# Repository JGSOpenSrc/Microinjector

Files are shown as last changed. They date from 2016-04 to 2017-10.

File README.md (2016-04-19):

# Microinjector
This repository contains the design files for a 3-D printable open hardware automated syringe pump, along with software to control the syringe pump over a serial port connection or via TTL logic. The original designs were published in a paper on the online journal PLOS ONE, and there are submodules of the relelvant repositories here.
# About
The design presented here is intended to allow for precise injection of liquid volumes from a high quality syringe with microliter precision (hence the name, microinjector). However the mechanical designs are easily adapted to syringes of other sizes (see the linear_actuator scripts or check out the submodules for more info).

The software in control runs on an Arduino in tandem with an Adafruit Motorshield (V2), using the motor shield library. Currently, calibration is performed by performing manual trials and tuning static constants in the arduino sketch to achieve desired levels of accuracy.

# Dependencies
- OpenSCAD is required to generate the models from the .scad files. You can download it from www.openscad.org.

- The Arduino IDE is required to compile and download the control script to the hardware (unless that is you have your own toolchain). Download it from www.arduino.c.

- The Adafruit Motor Shield e(VERSION 2!!) is needed to control the stepper motor used in the actuator. The best way to get it is grab it from github, to get it go to your arduino libraries folder and execute the command:

git clone https://github.com/adafruit/Adafruit_Motor_Shield_V2_Library Adafruit_Motorshield

# User's Guide #
The injector is controlled using the two limit switches, and either an open-drain (TTL) connection or a serial port connection (such as USB). The front limit switch is used to "prime" the injector, bringing it out of the reset state, and the rear limit switch is used to reset the position of the injector. The TTL pin and serial port are used to issue injection commands to the injector.

## Key Terms ##
- Zero-stroke: a configuration where the carriage is pressed up against the rear limit switch, at the motor end of the injector.
- Mid-stroke: a configuration where the carriage is in between the rear and front limit switch.
- Full-stroke: a configuration where the carriage is pressed up against the front limit switch, at the syringe end of the injector.
- Halt: a state where the injector is not primed and will ignore any injection commands. The halt state occurrs following reset, or once the injector reaches the zero-stroke or mid-stroke position
- Wait: a state where the injector is primed and will accept an injection command. The wait state occurrs when the front limit switch is pressed while in the halt state. Note, the injector must be in either the mid-stroke or zero-stroke position.

## Priming the Injector ##
After powering on, or following the assertion of reset, the injector will enter the halt state and will ignore any incoming injection request. To prime the injector, press the front limit switch once; this will put the injector in the wait state.

## Injecting via Serial Command ##
The serial port is configured run at 115200 baud, with 8 data bits, 1 stop bit, and null parity. To request an injection, send the string "inject" (without quotations) followed by a newline character.

## TTL Injection Trigger ##
The TTL pin interface is a two wire connection (signal and ground). An injection request is interpreted as a high-to-low transition on digital pin 5. The pin has an internal pull-up resistor and is 5V or 3V3 tolerant.

## Calibrating the IR Sensor ##
The injector uses an infrared emitter-detector pair to control the injection volume. Following an injection request, the motor will step forward until liquid is detected. While in the wait state, if the liquid remains for a certain amount of time then the injector will withdraw the liquid. This delay is set by a constant in the control.ino sketch.

The sensor consists of a photo-diode emitter and a photo-transistor detector. The detector is wired as an open-collector output; hence, when there is high IR absorption between the pair, the output of the sensor is a higher voltage, while when there is low absorption, the output of the sensor is a lower voltage.

For the sensor to work properly, two constants need to be calibrated in the control.ino sketch. 
- `const int high_to_low = ; // a low threshold, used to detect the presence of liquid`
- `const int low_to_high = ; // a high threshold, used to detect the absence of liqui`

Following reset, the injector will compute an average of ten IR readings, and determine the initial state of the liquid. If the average value is between the two thresholds, then the injector will not run (since it cannot determine the initial state). The average reading and the inferred initial state is printed to the serial port on every startup, and this output can be used to calibrate or troubleshoot the IR sensor.

## Wiring Configuration ##
For the injector to operate properly, there are three components that need to be connected to the arduino: the stepper motor, the limit switches, and the infrared liquid sensor.

### Motor Connection ###
The stepper motor uses a four wire bi-polar connection to the motor shield.

Motor Wire | Arduino Terminal
-----------|-----------------
Green      | M1
Black      | GND
Blue       | GND
Red        | M2

### Limit Switches ###
The limit switches connect to the motor shield by a split-end ribbon cable. The wires of the ribbon are numbered sequentially starting with the red wire being 1.

Ribbon Wire | Arduino pin
------------|------------
1           | GND
2           | Digital pin 10
3           | Digital pin 9

### IR Sensor ###
The infrared sensor is a 3 wire interface, consisting of 5V, GND, and an analog input.

Connector Position | Wire Color | Arduino Pin
-------------------|------------|------------
1                  | Black      | GND
2                  | White      | 5V
3                  | Grey       | Analog pin 0

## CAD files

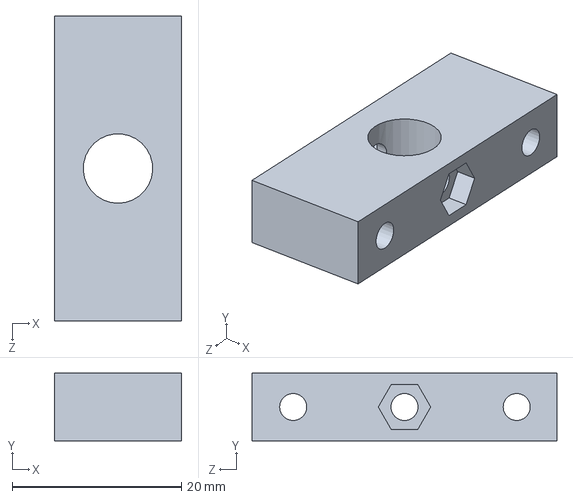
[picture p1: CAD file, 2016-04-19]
solidworks/limit_switch_block.SLDPRT
15.0 x 8.00 x 36.0 mm

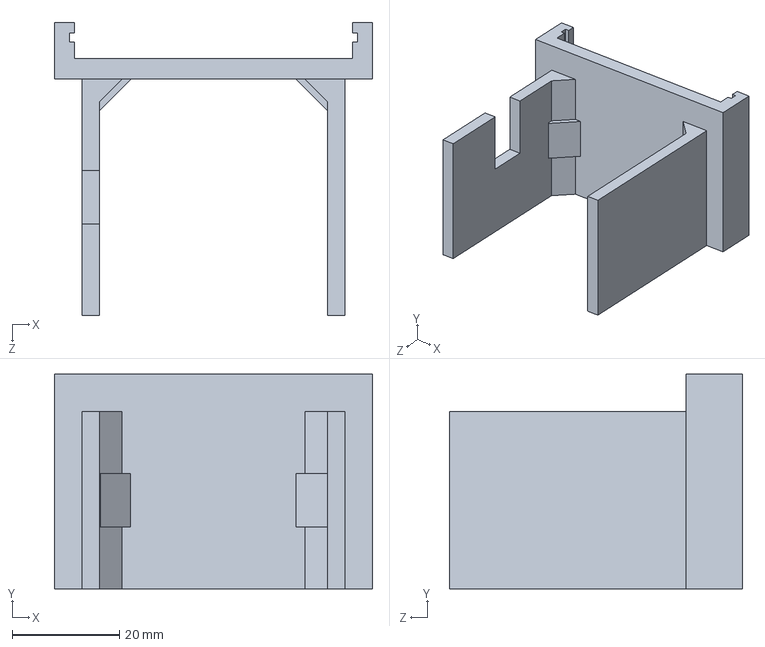
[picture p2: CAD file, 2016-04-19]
solidworks/arduino_mount.SLDPRT
59.2 x 40.0 x 54.5 mm

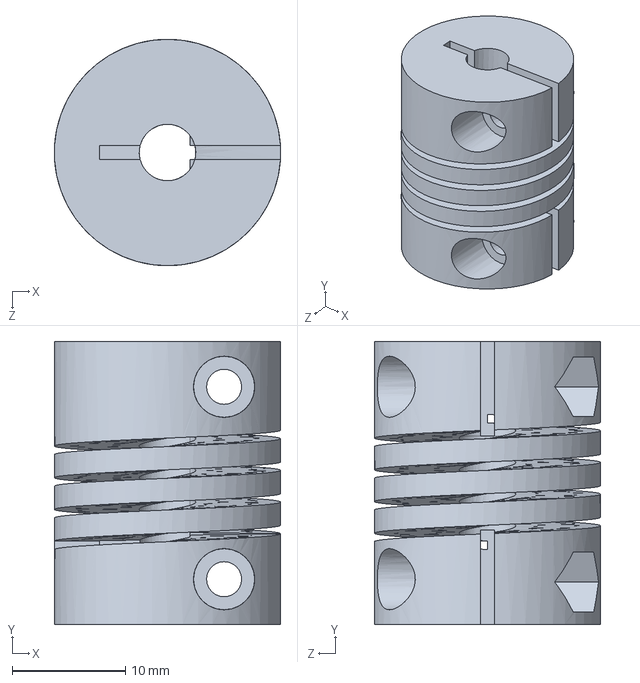
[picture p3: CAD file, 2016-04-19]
solidworks/shaft_coupler.SLDPRT
20.0 x 25.0 x 20.0 mm

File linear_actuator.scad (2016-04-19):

// Copyright 2013 Michigan Technological University
// Author: Jerry Anzalone
// This design was developed as part of a project with
// the Michigan Tech Open Sustainability Technology Research Group
// http://www.appropedia.org/Category:MOST
// It is released under CC-BY-SA
// includes may be found at http://github.com/mtu-most/most-scad-libraries

include<most-scad-libraries/fasteners.scad>
include<most-scad-libraries/steppers.scad>
include<most-scad-libraries/bearings.scad>

$fn = 96;

render_part(5);

module render_part(part_to_render) {
	if (part_to_render == 1) end_motor();

	if (part_to_render == 2) end_idler();

	if (part_to_render == 3) carriage();

	if (part_to_render == 4) carriage_syringe_pump();

	if (part_to_render == 5) clamp_syringe_pump();

	if (part_to_render == 6) {
		for (i = [-1, 1])
			translate([i * (d_guide_rod + 2.5), 0, 0])
				syringe_hook();
	}

	if (part_to_render == 7) {syringe_plunger_retainer();}

	if (part_to_render == 8) syringe_bungie();
}

// [x, y, z] = [l, w, t]

/*

No moving motor!
Simple loading
Simple cleaning
Protect motor
Secure plunger

*/

d_nozzle = 0.75;

motor = NEMA17;
cc_guides = 65;

d_lead_screw = d_M5_screw;
d_lead_nut = d_M5_nut;
h_lead_nut = h_M5_nut;
od_antibacklash_spring = 7;
l_antibacklash_spring = 9;

offset_guides = 3.5; // offset from centerline of motor shaft towards top (+y)
d_guide_rod = 8.2; // 8mm guide rods
guide_bearing = bearing_lm8uu;
pad_guide_bearing_radius = 3;

pad_guide_ends = 3; // backing material behind ends of guide rods
pad_guide_radius = 3; // material surrouding guide rods and bearings
t_motor_mount = 12;
w_ends = motor[0];
l_ends = cc_guides + d_guide_rod + 2 * pad_guide_radius;
xy_aspect = l_ends / w_ends; // needed to scale rounded box
t_motor_end = 25;
idler = bearing_625;
t_idler_end = 20;

t_carriage = guide_bearing[2] + 6;
t_syringe_clamp = 5;


d_clamp_screw = d_M3_screw;
d_clamp_screw_cap = d_M3_cap;
d_clamp_screw_nut = d_M3_nut;

// following for attachments


// syringe pump:
d_plunger = 9.5; // diameter of the plunger end
d_syringe = 8.2; // diameter of the syringe body - sets size of syringe holder
t_hook = 3; // thickness of the hook for securing syringe to actuator
t_syringe_flange = 2.85; // thickness of the rim around the diameter of the syringe near the punlger
standoff = 0.8 * t_syringe_flange;
d_plunger_max = 16; // this sets the spacing for screws on the plunger retainer and carriage
d_plunger_retainer = d_plunger_max + 12;


module end_motor() {
	difference() {
		union() {
			rod_clamps(t_motor_end, pad_guide_ends);

			// motor plate
			difference () {
				translate([0, 0, (t_motor_mount - t_motor_end) / 2])
					cube([l_ends - (l_ends - cc_guides) - 1, w_ends, t_motor_mount], center = true);

				clamp_relief(t_motor_end, pad_guide_ends);
			}
		}

		// motor mount holes
		translate([0, 0, -t_motor_end / 2])
			rotate([0, 0, 45])
				NEMA_X_mount(
					height = t_motor_end,
					l_slot = 1,
					motor = motor);

		// keyhole opening for motor mount screws
		// for (i = [-1, 1])
		//	translate([i * motor[3] / 2, -motor[3] / 2, 0])
		//		cylinder(r = 2.5, h = 5, center = true);
	}
}

module end_idler() {
	difference() {
		union() {
			rod_clamps(t_idler_end, pad_guide_ends);

			// idler bearing housing

			difference () {
				translate([0, -((w_ends + idler[0]) / 2 - idler[0]) / 2, 0])
					cube([l_ends - (l_ends - cc_guides), (w_ends + idler[0]) / 2, t_idler_end], center = true);

				clamp_relief(t_motor_end, pad_guide_ends);
			}

		}

		// outboard idler bearing
		translate([0, 0, -t_idler_end / 2])
			cylinder(r = idler[0] / 2 + 0.01, h = idler[2] * 2, center = true);

		// inboard idler bearing
		translate([0, 0, t_idler_end / 2])
			cylinder(r = idler[0] / 2 + 0.01, h = idler[2] * 2, center = true);

		// lead screw
		translate([0, 0, idler[2] + 0.2])
			cylinder(r = d_lead_screw / 2, h = t_idler_end, center = true);

		end_mount_holes(t_idler_end + 1, d_M3_screw);
	}

    // loop to mount the syringe body
    y_clamp_center = idler[0] / 2 + d_syringe / 2;
    difference(){

        difference(){
            translate([0, y_clamp_center - d_syringe / 2,
                        t_idler_end / 2 - t_syringe_clamp / 2])
                cube([d_syringe + 8, d_syringe + t_syringe_clamp / 2,
                        t_syringe_clamp], center = true);

            union(){
                translate([0, y_clamp_center,
                            t_idler_end / 2 - t_syringe_clamp / 2])
                    cylinder(r = d_syringe / 2, h = t_syringe_clamp, center = true);

                translate([0, y_clamp_center + d_syringe / 2,
                            t_idler_end / 2 - t_syringe_clamp / 2 ])
                    cube([d_syringe, d_syringe,
                            t_syringe_clamp], center = true);
            }
        }
    	translate([0, 0, t_idler_end / 2])
			cylinder(r = idler[0] / 2 + 0.01, h = idler[2] * 2, center = true);
    }

}


module carriage_body() {
	hull() {
		for (i = [-1, 1])
			translate([i * cc_guides / 2, offset_guides, 0])
				cylinder(r = guide_bearing[0] / 2 + pad_guide_bearing_radius, h = t_carriage, center = true);

		cylinder(r = od_antibacklash_spring / 2 + pad_guide_radius, h = t_carriage, center = true);
	}
}

module carriage_relief() {
	for (i = [-1, 1])
		translate([i * cc_guides / 2, offset_guides, 0]) {
			// guide rods
			cylinder(r = d_guide_rod / 2 + 0.5, h = t_carriage + 2, center = true);

			// guide bearings
			cylinder(r = guide_bearing[0] / 2, h = guide_bearing[2], center = true);

			translate([i * (guide_bearing[0] / 2 - 2), -(guide_bearing[0] / 2 - 2), , 0])
				cylinder(r = guide_bearing[0] / 2, h = guide_bearing[2], center = true);
	}

	// nut trap for fixed nut
	hull()
		for (i = [0, -1])
			translate([0, i * t_carriage, -t_carriage / 2 + 2])
				rotate([0, 0, 30])
					cylinder(r = d_lead_nut / 2, h = h_lead_nut, $fn = 6);

	// lead nuts and anti-backlash spring
	hull()
		for (i = [0, 1])
			translate([0, i * -20, -t_carriage / 2 + h_lead_nut + 4])
				rotate([0, 0, 30])
					cylinder(r = d_lead_nut / 2, h = l_antibacklash_spring + h_lead_nut / 2, $fn = 6);

	translate([0, 0, -t_carriage / 2 + h_lead_nut + 4])
		rotate([0, 0, 30])
			cylinder(r = d_lead_nut / 2, h = l_antibacklash_spring + h_lead_nut, $fn = 6);

	// lead screw
	cylinder(r = d_lead_screw /2 + 0.5, h = t_carriage + 2, center = true);
}

module carriage_support() {
	// floors for holes
	for (i =[-1, 1])
		translate([i * cc_guides / 2, offset_guides, guide_bearing[2] / 2])
			cylinder(r = guide_bearing[0] / 2 - 1, h = 0.2);

	translate([0, 0, -t_carriage / 2 + h_lead_nut + 4 + l_antibacklash_spring + h_lead_nut])
		cylinder(r = d_lead_nut / 2, h = 0.2);

	translate([0, 0, -t_carriage / 2 + h_lead_nut + 4 + l_antibacklash_spring + h_lead_nut / 2])
		cylinder(r = d_lead_nut / 2 + 1, h = 0.2);

	translate([0, 0, -t_carriage / 2 + 2 + h_lead_nut])
		cylinder(r = d_lead_nut / 2 + 1, h = 0.2);

	// filler for gaps
	for (i =[-1, 1])
		translate([i * cc_guides / 2, offset_guides, 0])

			difference() {
				cylinder(r = guide_bearing[0] / 2 + pad_guide_bearing_radius, h = t_carriage, center = true);

				cylinder(r = guide_bearing[0] / 2 + pad_guide_bearing_radius - d_nozzle, h = t_carriage + 2, center = true);
			}
}

module carriage() {
	union() {
		difference() {
			carriage_body();

			carriage_relief();
		}
        //tabs for tripping end limit switch
        translate([cc_guides/2, - guide_bearing[0] / 2 -
            pad_guide_bearing_radius + 4, t_carriage / 2 - 3]){
            cube([15,5,t_carriage / 2 - guide_bearing[2] / 2]);
        }
		//carriage_support();
	}
}

module rounded_box(
	l1,
	l2,
	r_corner,
	height) {

	hull()
		for (i = [-1, 1])
			for (j = [-1, 1])
				translate([i * (l1 / 2 - r_corner), j * (l2 / 2 - r_corner), 0])
					cylinder(r = r_corner, h = height, center = true);
}

module clamp_body(thickness) {
	union() {
		for (i = [-1, 1])
			translate([i * cc_guides / 2, 0, 0])
				rounded_box(
					l1 = (l_ends - cc_guides),
					l2 = w_ends,
					r_corner = 3,
					height = thickness);

		// bottom
		//translate([0, (4 - w_ends) / 2, 0]) cube([cc_guides, 4, thickness], center = true);
	}
}

module clamp_relief(
	thickness,
	pad_ends) {
			// guide rods have backing, so are off the end of the body
			for (i = [-1, 1])
				translate([i * cc_guides / 2, offset_guides, pad_ends])
					cylinder(r = d_guide_rod / 2, h = thickness, center = true);

			// slots for clamping guide rods
			for (i = [-1, 1])
				translate([i * cc_guides / 2, offset_guides, 0])
					hull()
						for (j = [-0.25, 1])
							translate([0, j * w_ends, 0])
								cylinder(r = 0.5, h = thickness + 2, center = true);

			// holes for clamp screws
			translate([0, w_ends / 4 + offset_guides, 0]) {
				for (i = [-1, 1])
					for (j = [1]) {
						translate([i * cc_guides / 2, 0, j * (thickness - pad_ends) / 4])
							rotate([0, 90, 0])
								cylinder(r = d_clamp_screw / 2, h = (l_ends - cc_guides) * 2, center = true);
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

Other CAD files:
linear_actuator_A.scad

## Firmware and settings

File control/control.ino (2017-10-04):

#include<Wire.h>
#include<Adafruit_MotorShield.h>
#include "utility/Adafruit_MS_PWMServoDriver.h"

/* The amount of time, in seconds, that the injector will wait
   after an injection before retracting the liquid. */
#define TIMEOUT    10

/* I2C bus speed, is modified in setup() */
#define I2C_FREQ 400000L

/* Buffer length used for storing / sending messages over UART
  and for doing general string comparisons*/
#define BUFFER_LEN 256

/* Defines for IO port names*/
#define S1 9
#define S2 10
#define SOLENOID_ENERGIZE 8
#define BOUNCE_DELAY 100
#define TTL_INCREMENT_PIN 5
#define IR_SENSOR_PIN A0
#define INJECT_STEP_COUNT 20000 // Adjust this to achieve the desired injection unit volume

// Motor constants
static const int motor_speed = 600;
static const int steps_per_rev = 200;
// ADC threshold values for detecting liquid by electrical conductivity
static const int high_to_low = 700;
static const int low_to_high = 900;

/* Enumeration of possible states */
enum STATE{
  wait,
  inject,
  withdraw
};

/* Enumeration of possible positions */
enum POSITION{
  zero_stroke,
  mid_stroke,
  full_stroke
};

Adafruit_MotorShield AFMS = Adafruit_MotorShield();             // Create the motor shield object with the default I2C address.

Adafruit_StepperMotor *motor = AFMS.getStepper(steps_per_rev, 1);// Connect a stepper motor with 200 steps per revolution (1.8 degree)
                                                                // to motor port #2 (M3 and M4).

bool stopflag = false;                                          // Emertency stop flag that is set by the forward limit switch. Prevents damage to injector.
bool reset = true;                                              // Reset flag used to initialize the position of the injector.
bool is_empty;                                                  // Flag used for detecting


int steps = 0;                                                  // Number of steps left for the actuator to complete before its current command is finished
int volume = 0;                                                 // Volume of fluid requested for injection by serial communication interface.
enum POSITION injector_pos;                                     // General position of the injector at power-on reset. Can be zero-stroke, mid-stroke, or full-stroke.
enum STATE injector_state;                                      // Control variable. Can be halt, reset_pos, wait, or inject
char input_buffer[BUFFER_LEN];                                  // Serial input buffer, used to store serial data and to parse commands.
char output_buffer[BUFFER_LEN];                                 // Serial output buffer, used to store messages which will be sent out to the serial port.

void setup() {

                                                                // initialize message buffer
  int i;
  for(i = 0; i < BUFFER_LEN; i++){
    output_buffer[i] = 0;
  }
                                                                // setup serial port
  Serial.begin(115200);
  Serial.setTimeout(1000);

  /* Set up pin modes for safety / limit switches */
  pinMode(S1, INPUT_PULLUP);                                    // pole 1 of safety switch 1
  delay(10);                                                    // For some reason this delay is necessary
  pinMode(S2, INPUT_PULLUP);                                    // Configure the S2 with an internal pullup.
  delay(10);

  pinMode(SOLENOID_ENERGIZE, OUTPUT);                           // Set solenoid mosfet driver to output
  digitalWrite(SOLENOID_ENERGIZE, LOW);
  delay(500);

  int value = analogRead(IR_SENSOR_PIN);
  sprintf(output_buffer, "Conductivity sensor reads %d.", value);
  Serial.println(output_buffer);
  if(value < high_to_low) is_empty = true;

  /* Determine the initial state of the micoinjector */
  if (!digitalRead(S1) && digitalRead(S2)){                     // Actuator is initally in zero_stroke position
    injector_pos = zero_stroke;
    injector_state = wait;
    Serial.println("Acuator initial position is zero-stroke.");
  }
  else if (digitalRead(S1) && digitalRead(S2)){                // Actuator is initially in full_stroke position
    injector_pos = mid_stroke;
    injector_state = withdraw;
    // Switch the solenoid to source liquid
    digitalWrite(SOLENOID_ENERGIZE, HIGH);
    delay(500);
    Serial.println("Actuator initial position is mid-stroke");
  }
  else if (digitalRead(S1) && !digitalRead(S2)){                 // Actuator is initially in mid_stroke
    injector_pos = full_stroke;
    injector_state = withdraw;
    // Switch the solenoid to source liquid
    digitalWrite(SOLENOID_ENERGIZE, HIGH);
    delay(500);
    Serial.println("Actuator initial position is full-stroke");
  }
  else{
    Serial.println("Actuator initial position unknown...");
    sprintf(output_buffer, "S1 %d S2 %d", digitalRead(S1), digitalRead(S2));
    Serial.println(output_buffer);
    Serial.println("There is a problem with the limit switches.");
    Serial.println("Fix the switches and then reset or reprogram.");
    while(1);
  }

  /* Setup of the TTL injection trigger,
  this requires a digital pin, and configuration of a hardware counter. */
  pinMode(TTL_INCREMENT_PIN, INPUT_PULLUP);
                                                                // Initialize Counter 1, used to track TTL pulses on the TTL_INCREMENT_PIN
  TCCR1A = 0x00;                                                // Configures Counter 1 to run in normal mode, with no output flags.
  TCCR1B = (1<<CS02)|(1<<CS01);                                 // Set the counter clock source to the TTL_INCREMENT_PIN falling edge.
  TCNT1 = 0;                                                    // Reset the counter output register.

  AFMS.begin();                                                 // Initialize motor
  motor->setSpeed(motor_speed);

  stopflag = false;

  TWBR = ((F_CPU / I2C_FREQ) - 16) / 2;                         // Change the I2C frequency
}

void loop() {
  if (wait == injector_state){                             // wait state. The injector is waiting for an injection commmand form the user.
    liquid_detected();
    if(injection_requested()){
      injector_state = inject;
      Serial.println("Injecting.");
    }
  }

  else if (inject == injector_state){                           // inject state. The injector is currently stepping forward.
    /* If S2 is depressed, then the syringe is empty. */
    if (!digitalRead(S2)){
      motor->release();
      injector_pos = full_stroke;
      injector_state = withdraw;
      digitalWrite(SOLENOID_ENERGIZE, HIGH);
      delay(500);
      Serial.println("End of actuator reached. Refilling syringe.");
    }

    /* If the liquid is detected, cease injecting and wait */
    else if (liquid_detected()){
      motor->release();
      injector_state = wait;
      Serial.println("Liquid detected, injection complete.");
    }

    else {
      motor->step(1, FORWARD, SINGLE);
      if(digitalRead(S1)){
        injector_pos = mid_stroke;                              // S1 high -> position is mid-stroke.
      }
    }
  }

  else if (withdraw == injector_state){                         // withdraw state. The injecgtor is currently stepping backwards
    /* if S1 is depressed, then the syringe is full */
    if(!digitalRead(S1)){
      motor->release();
      digitalWrite(SOLENOID_ENERGIZE, LOW);
      Serial.println("Syringe has been filled.");
      injector_pos = zero_stroke;
      delay(500);
      injector_state = wait;
    }
    /* Step backward to fill the syringe */
    else {
        motor->step(1, BACKWARD, SINGLE);
    }
  }
}

/** returns true if liquid is detected by the conductivity sensor */
bool liquid_detected(){
  int val = analogRead(IR_SENSOR_PIN);
  bool detected = is_empty && (val > low_to_high)  || !is_empty && (val > high_to_low);
  if (!detected && !is_empty) {
    Serial.println("Liquid consumed.");
  }
  is_empty = !detected;
  return detected;
}

/*
  Checks the serial port for an injection command, and also checks the hardware
  counter for a TTL pulse (either can be implemented). Returns true if an injection
  command has been received.
*/
bool injection_requested(){
  bool inject = false;
  int rc = read_line(input_buffer);
  /* Handle requests sent to the serial port. */
  if(0 < rc){
    /* Check to see if the string is a recognized command. */
    if(0 == strcmp(input_buffer, "inject")){

      inject = true;
      steps = INJECT_STEP_COUNT;
      sprintf(output_buffer,
              "Injection command received");
      Serial.println(output_buffer);
    }

    else if (0 < strtol(input_buffer, NULL, 10)) {

      inject = true;

      steps = strtol(input_buffer, NULL, 10);
      sprintf(output_buffer,
              "Injection command received for %d steps", steps);
      Serial.println(output_buffer);
    }

    else {
      /* The string received was no good */
      inject = false;
      sprintf(output_buffer,
              "ERROR invalid command received");
      Serial.println(output_buffer);
      Serial.print(input_buffer);
    }
  }

  /* Check the counter for a TTL pulse, which singals an injection request */
  else if(0 < TCNT1) {
    TCNT1--;
    inject = true;
    sprintf(output_buffer,
            "TTL pulse received");
    Serial.println(output_buffer);
  }
  return inject;
}

/* read_line

  A quick and dirty method for retrieving data segmented by newline characters
  from the serial port. Writes the data to the buffer provided.
*/

int read_line(char buff[] ){
  int rc = 0;

  char* strptr = buff;

  bool overflow = false;

  if (Serial.available()){
    rc = Serial.readBytesUntil( '\n', buff, BUFFER_LEN - 1);
    buff[rc] = '\0';
  }
  return rc;
}

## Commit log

2016-04-04 First commit of files. Design scripts for two revisions of the microinjector design, including a submodule of the source repo for the design files (linear-actuator), and a submodule for OpenSCAD depe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
    [!.dxf, #.dxf, +.dxf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]
2016-04-04 Readded the most-scad-libaries submodule so it is linked properly, reflected this change in the two linear actuator include statements
    [!.dxf, #.dxf, +.dxf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]
2016-04-05 Restructured folders to remove empty directories, renamed linear_actuator scripts to be syringe model agnostic
    [linear_actuator_A.scad, linear_actuator_B.scad]
2016-04-07 Changed defines for state and position data to enumerations, removed defines for calibration constants and replaced with typed static constants, adjusted spacing of code for readability.
    [control.ino]
2016-04-07 Fixed typo in position and state enumeration declaration
    [control.ino]
2016-04-15 implemented modifications to control.ino to incorporate IR sesnor for liquid-level based control of the pump
    [linear_actuator_A.scad]
2016-04-19 Added improvements to linear_actuator.scad script to optimize build, removed redundant SCAD scripts
    [linear_actuator.scad, linear_actuator_B.scad]
2016-04-19 Updated control.ino to incorporate IR sensor control, and imported parts designed in solidworks.
    [arduino_mount.SLDPRT, limit_switch_block.SLDPRT, shaft_coupler.SLDPRT]
2016-04-19 Removed redundant .SCAD files, made improvements to linear_actuator.SCAD design to optimize build, added solidworks files for parts not designed using OpenSCAD
    [arduino_mount.SLDPRT, limit_switch_block.SLDPRT, linear_actuator.scad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]
2017-03-13 started adding code for solenoid switch
2017-03-14 Implemented automated refilling of the syringe via control of a solenoid to source liquid during the withdraw operation. This greatly simplified the control code
2017-10-04 Reworked liquid detection. Injections are prompted by user, end when liquid is detected. Modified some of the messages sent by the injector over its serial port for clarity
    [control.ino]
